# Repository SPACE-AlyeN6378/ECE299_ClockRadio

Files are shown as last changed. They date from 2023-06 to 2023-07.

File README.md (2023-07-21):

# Raspberry Pi Pico: Clock Radio
Clock radio is driven by Raspberry Pi Pico
## Configuration
### NORMAL MODE

- Button 1 - Mute
- Button 2 - Toggle 12-24 hour format
- Button 3 - Set time
- Button 4 - Set alarm
- Rotary button - Toggle between changing frequency/Volume 
- Turn knob - Change frequency/volume

### SET TIME MODE

- Button 1 - Menu Left
- Button 2 - Menu Right 
- Button 3 - Cancel
- Button 4 - Cancel setting & change alarm
- Rotary button - Confirm
- Turn knob - Change time

### SET ALARM MODE

- Button 1 - Menu Left
- Button 2 - Menu Right 
- Button 3 - Time settings
- Button 4 - Alarm on/off
- Rotary button - Confirm and exit
- Turn knob - Change alarm time

### WHILE ALARM IS RINGING

- Button 1 - Stop alarm
- Button 2 - Snooze

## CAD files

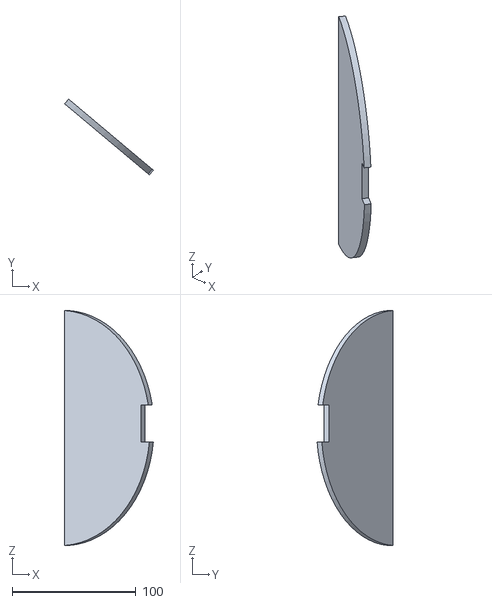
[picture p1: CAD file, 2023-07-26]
3d_enclosure/preview/sidepanel.stl
71.6 x 61.2 x 189.7

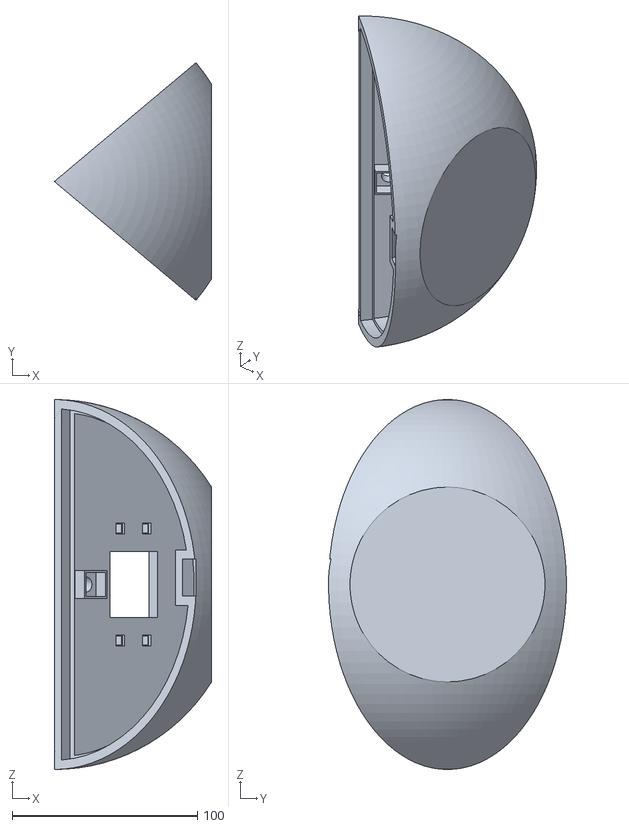
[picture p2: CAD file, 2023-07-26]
3d_enclosure/preview/Housing.stl
85.0 x 128.5 x 200.0

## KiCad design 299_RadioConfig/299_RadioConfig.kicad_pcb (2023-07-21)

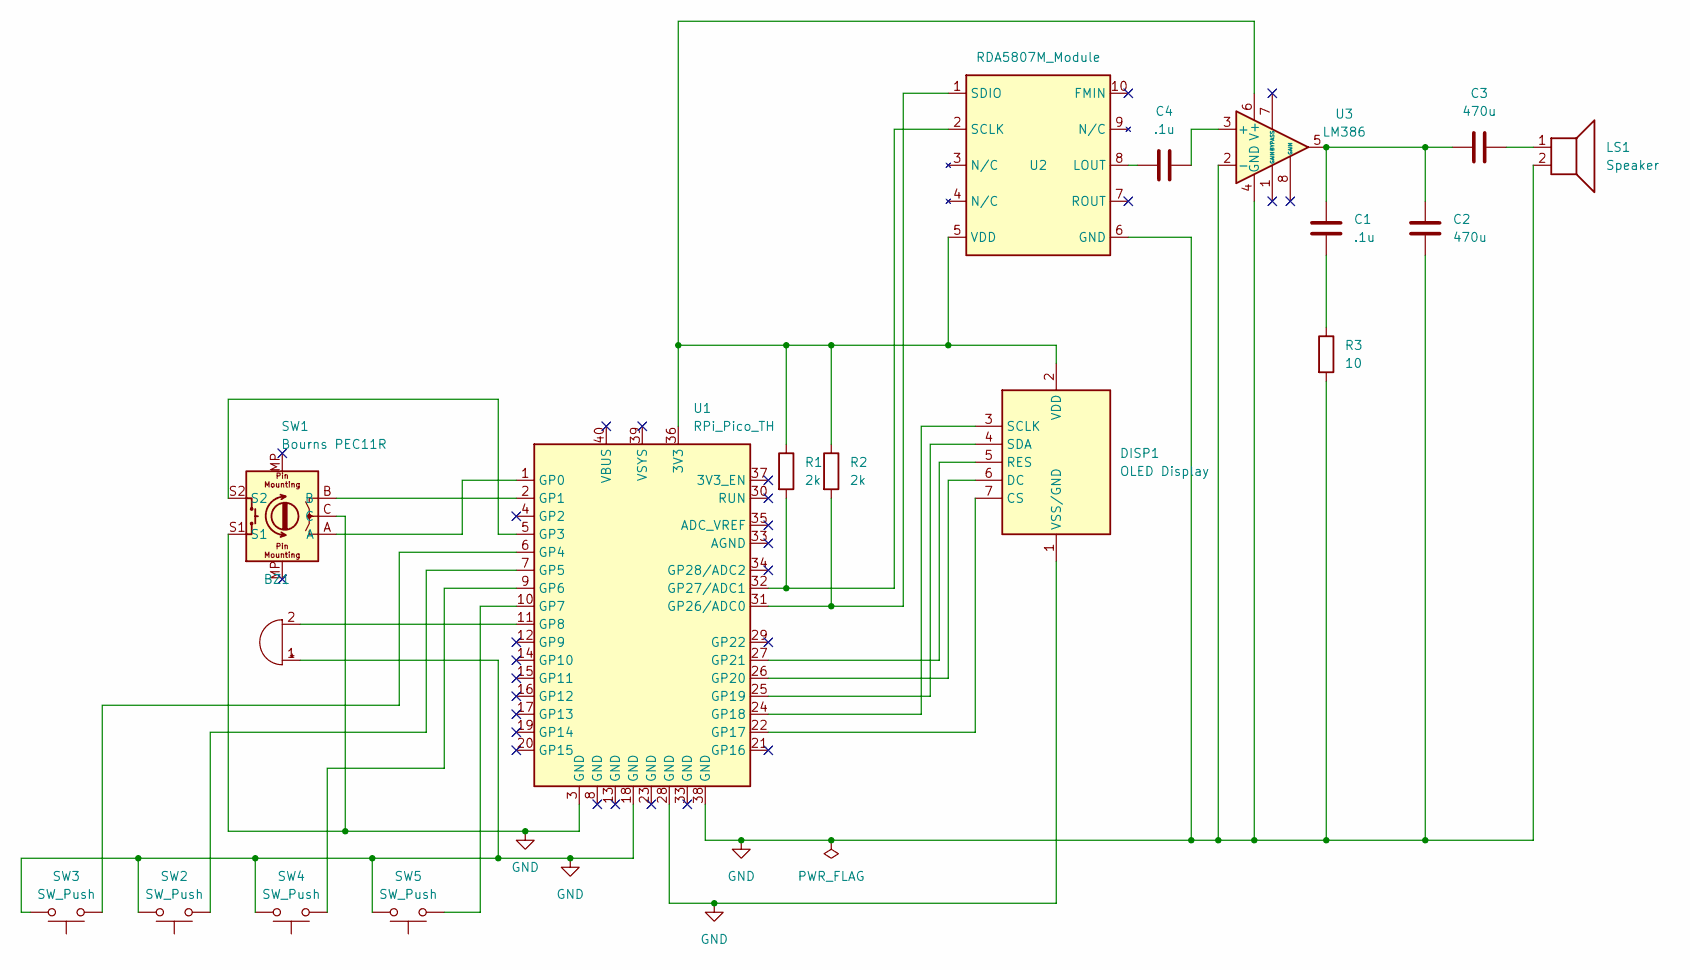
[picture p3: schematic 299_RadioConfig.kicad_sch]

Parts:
BZ1: (no value)
C1, C4: .1u; C_Axial_L3.8mm_D2.6mm_P7.50mm_Horizontal
C2: 470u; C_Radial_D6.3mm_H11.0mm_P2.50mm
C3: 470u; C_Radial_D5.0mm_H11.0mm_P2.00mm
DISP1: OLED Display; PinHeader_1x07_P2.54mm_Vertical
LS1: Speaker; TerminalBlock_Phoenix_MKDS-1,5-2_1x02_P5.00mm_Horizontal
R1, R2: 2k; R_Axial_DIN0207_L6.3mm_D2.5mm_P10.16mm_Horizontal
R3: 10; R_Axial_DIN0207_L6.3mm_D2.5mm_P10.16mm_Horizontal
SW1: Bourns PEC11R; RotaryEncoder_Alps_EC12E-Switch_Vertical_H20mm_CircularMoun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
SW2, SW3, SW4, SW5: SW_Push; PinHeader_1x02_P2.54mm_Vertical
U1: RPi_Pico_TH
U2: RDA5807M_Module; RDA5807M_Module_TH
U3: LM386; DIP-8_W7.62mm

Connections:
GND: BZ1.1 (-), C2.1, DISP1.1 (VSS/GND), LS1.2, R3.2, SW1.C, SW1.S1, SW2.2, SW3.2, SW4.2, SW5.2, U1.3 (GND), U1.18 (GND), U1.28 (GND), U1.38 (GND), U2.6 (GND), U3.2 (-), U3.4 (GND)
unnamed: C1.1, C2.2, C3.1, U3.5
unnamed: C1.2, R3.1
unnamed: C3.2, LS1.1
unnamed: C4.1, U2.8 (LOUT)
unnamed: C4.2, U3.3 (+)
unnamed: DISP1.2 (VDD), R1.1, R2.1, U1.36 (3V3), U2.5 (VDD), U3.6 (V+)
unnamed: DISP1.3 (SCLK), U1.24 (GP18)
unnamed: DISP1.4 (SDA), U1.25 (GP19)
unnamed: DISP1.5 (RES), U1.27 (GP21)
unnamed: DISP1.6 (DC), U1.26 (GP20)
unnamed: DISP1.7 (CS), U1.22 (GP17)
unnamed: R1.2, U1.32 (GP27/ADC1), U2.2 (SCLK)
unnamed: R2.2, U1.31 (GP26/ADC0), U2.1 (SDIO)
unnamed: SW1.A, U1.1 (GP0)
unnamed: SW1.B, U1.2 (GP1)
unnamed: SW1.S2, U1.5 (GP3)
unnamed: SW2.1, U1.7 (GP5)
unnamed: SW3.1, U1.6 (GP4)
unnamed: SW4.1, U1.9 (GP6)
unnamed: SW5.1, U1.10 (GP7)
unnamed: BZ1.2 (+), U1.11 (GP8)

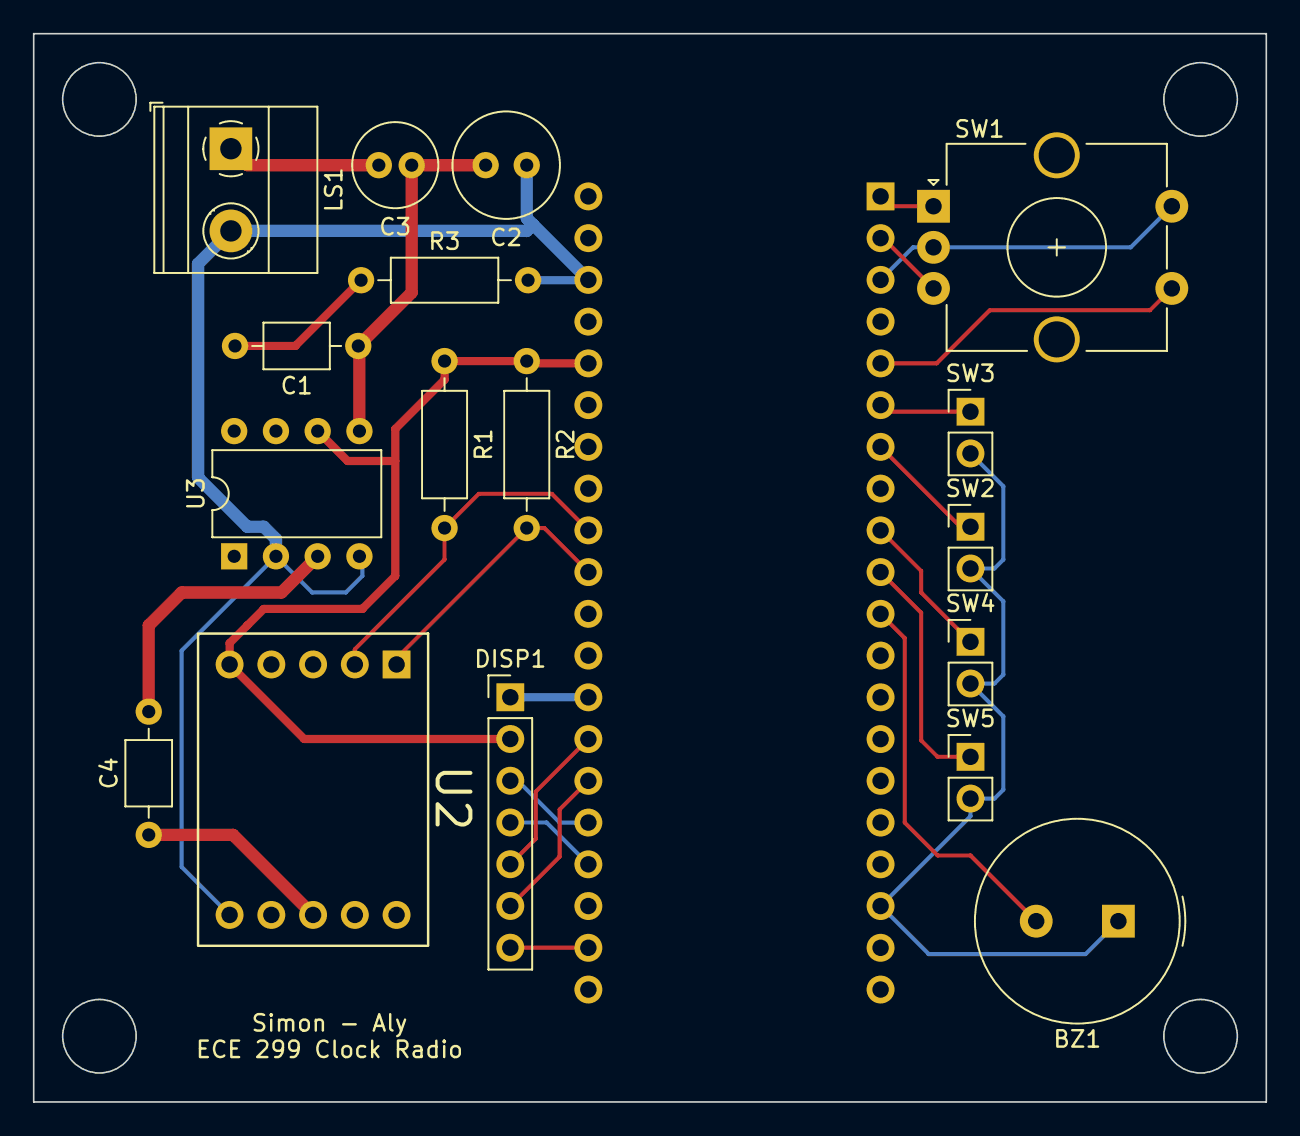
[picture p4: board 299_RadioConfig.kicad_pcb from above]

Board: 2 copper layers, 75.0 x 65.0 mm, 18 parts (1 on the bottom side), 22 nets.

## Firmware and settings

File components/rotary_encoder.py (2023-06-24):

from machine import Pin
from components.button import Button

class RotaryEncoder:
    states_order = ((0, 1), (0, 0), (1, 0), (1, 1)) # order in clockwise direction

    # Sequences (using indexes from the 'states_order' list above)
    counterclockwise = [2, 1, 0, 3]
    clockwise = [0, 1, 2, 3]

    def __init__(self, pin_A, pin_B, btn_pin, ccw_turn, cw_turn, on_push) -> None:
        # Pins
        self.pin_A = Pin(pin_A, Pin.IN, Pin.PULL_UP)
        self.pin_B = Pin(pin_B, Pin.IN, Pin.PULL_UP)

        # Function Callbacks
        self.ccw_turn = ccw_turn
        self.cw_turn = cw_turn

        # The last state, the present state and the register
        self.last_state = self.states_order[3]
        self.present_state = self.states_order[3]
        self.register = [] # Which holds a collection of indexes

        # Initialize the interrupts
        self.pin_A.irq(trigger=Pin.IRQ_RISING | Pin.IRQ_FALLING, handler=self.callback)
        self.pin_B.irq(trigger=Pin.IRQ_RISING | Pin.IRQ_FALLING, handler=self.callback)

        # Initialize the button
        self.button = Button(btn_pin, on_push=on_push)


    def callback(self, pin):
        self.present_state = (self.pin_A.value(), self.pin_B.value())

        # Collect the index values as long as there is a state change
        if self.last_state != self.present_state:
            self.register.append(self.states_order.index(self.present_state))
            self.last_state = self.present_state

            # If the sequence is maintained, just take the last four values
            if self.register[-4:] == self.clockwise:
                self.cw_turn()
                self.register.clear()
            elif self.register[-4:] == self.counterclockwise:
                self.ccw_turn()
                self.register.clear()

    

        

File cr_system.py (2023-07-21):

from components.display import Display
from components.fm_radio import Radio
from components.rotary_encoder import RotaryEncoder
from components.button import Button
from clock import Clock


# ENUMS (for readability purposes) --------------------------

# Modes
NORMAL = 0
TIME_SETTINGS = 1
ALARM_SETTINGS = 2
RADIO_SCHEDULE_SETTINGS = 3

# Type of clock
MAIN_CLOCK = 5
TEMP_CLOCK = 6
ALARM = 7
PLAY_RADIO = 8
MUTE_RADIO = 9

# Pointer movement direction
LEFT = False
RIGHT = True

class CRSystem:
    
    def __init__(self, btn1_pin, btn2_pin, btn3_pin, btn4_pin, rt_btn_pin, rt_pinA, rt_pinB):
        # MODES AND SETTINGS ----------------------------------------
        self.twelve_hr_ft = True
        self.pointer = 0 # The pointer is used to highlight selection
        self.change_vol_mode = False
        self.mode = NORMAL

        # TIMES ----------------------------------------------------
        self.clock = Clock(0, 0)
        self.temp_clock = Clock(0, 0) # To set to a new time while the main clock is running
        
        
        # COMPONENTS ----------------------------------------------------
        self.screen = Display(18, 19, 21, 20, 17)
        self.knob = RotaryEncoder(rt_pinA, rt_pinB, rt_btn_pin, lambda: self.set_freq_vol(False), lambda: self.set_freq_vol(True), self.toggle_vol_control)
        self.button1 = Button(btn1_pin, self.mute)
        self.button2 = Button(btn2_pin, self.toggle_12_24)
        self.button3 = Button(btn3_pin, lambda: self.switch_mode(TIME_SETTINGS))
        self.button4 = Button(btn4_pin, lambda: self.switch_mode(ALARM_SETTINGS))
        
        # RADIO ---------------------------------------------------------
        self.volume = 11
        self.frequency = 100.3
        self.new_frequency = 100.3
        self.is_mute = False
        self.radio = Radio( self.frequency, self.volume, self.is_mute )
        
        # ALARM STATE ---------------------------------------------------
        self.alarm = False
        # If this countdown timer runs out, the alarm will stop and set it to snooze, unless the user hits STOP
        self.countdown = 0
        self.snooze = False
        self.alarm_time = Clock(0, 0)
        self.snooze_time = Clock(0, 0)
    
    # Set all the input configurations to default
    def default_config(self):
        self.pointer = 0
        self.change_vol_mode = False
        self.knob.ccw_turn = lambda: self.set_freq_vol(False)
        self.knob.cw_turn = lambda: self.set_freq_vol(True)
        self.knob.button.on_push = self.toggle_vol_control
        self.button1.on_push = self.mute
        self.button2.on_push = self.toggle_12_24
        self.button3.on_push = lambda: self.switch_mode(TIME_SETTINGS)
        self.button4.on_push = lambda: self.switch_mode(ALARM_SETTINGS)
    
    # A do-nothing function for restricting callback
    def do_nothing(self):
        pass

    # RADIO FUNCTIONALITY ---------------------------------------
    
    # To mute the radio
    def mute(self):
        if not self.alarm:
            self.is_mute = not self.is_mute
            if ( self.radio.SetMute( self.is_mute ) == True ):
                self.radio.ProgramRadio()
            
            
    # To change the volume level (not to be used in the knob)
    def set_volume(self, increment):
        if increment:
            if self.volume < 15:
                self.volume += 1
                
                if ( self.radio.SetVolume( self.volume ) == True ):
                    self.radio.ProgramRadio()
                
        else:
            if self.volume >= 1:
                self.volume -= 1
                
                if ( self.radio.SetVolume( self.volume ) == True ):
                    self.radio.ProgramRadio()
            
        
    # To change the radio frequency (not to be used in the knob)
    def set_frequency(self, increment):
        if increment:
            if self.frequency < 107.9:
                self.frequency += 0.1
                
                if ( self.radio.SetFrequency( self.frequency ) == True ):
                    self.radio.ProgramRadio()
                
        else:
            if self.frequency >= 88.1:
                self.frequency -= 0.1
                
                if ( self.radio.SetFrequency( self.frequency ) == True ):
                    self.radio.ProgramRadio()
                    
    # This is a function for the knob to change either the frequency or the volume, depending on the mode
    def set_freq_vol(self, increment):
        if self.change_vol_mode:
            self.set_volume(increment)
        else:
            self.set_frequency(increment)
                

    # To toggle between volume and frequency control
    def toggle_vol_control(self):
        self.change_vol_mode = not self.change_vol_mode
    
            
    # CLOCK FUNCTIONALITY ---------------------------------------

    # Changes the speed of the clock
    def change_speed(self, increment=True):
        if increment:
            self.clock.speed += 1
        else:
            self.clock.speed -= 1
            
    # Moves the pointer while setting the time/alarm/schedule
    def move_pointer(self, direction, lower_limit=0, upper_limit=9):
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

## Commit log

2023-06-24 codes redesigned as class structures
    [basicdisplay.py, button.py, clock.py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]
2023-07-04 Updated Radio Config, as ordered from JLCPCB
    [299_RadioConfig-B_Cu.gbr, 299_RadioConfig-B_Mask.gbr, 299_RadioConfig-B_Silkscreen.gbr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]
2023-07-26 Solidworks files
    Inclusion of parts, assembly, and drawing outlining relevant dimensions.
    [ClockRadio.SLDASM, ClockRadio.SLDDRW, Housing.SLDPRT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]
2023-07-26 Solidworks files moved in folder
    [ClockRadio.SLDASM, ClockRadio.SLDDRW, Housing.SLDPRT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]
2023-07-26 3D Files moved to folder
    [ClockRadio.SLDASM, ClockRadio.SLDDRW, Housing.SLDPRT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]
2023-07-26 STL added for preview
    [Housing.stl, sidepanel.stl]
